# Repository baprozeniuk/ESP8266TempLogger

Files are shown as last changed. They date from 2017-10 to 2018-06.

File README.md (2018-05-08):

# ESP8266 Temperature Logger
Designed and tested on a Lolin NodeMCU V3. Sends temperature over UDP from a DS18B20 connected to an ESP8266 microcontroller.

# Data Format
Temperature is sent in a single UDP packet with a payload of 12 bytes to a configurable host and port. 
First 6 bytes contain the MAC address of the ESP8266 as a unique identifier
Second 2 bytes contain a 16 bit unsigned integer to identify the sensor. Multiple Sensors are not yet supported, so this value is always 0x0000
Final 4 bytes contain a 32 bit floating point value from the sensor in Celsius 

# Configuration
The WiFi network configured in the ESP8266 EEPROM will be used by default. If you have previously programmed the microcontroller, the reset config switch should be activated on first boot. If you have previously programmed a WiFi network and do not reset the controller the host and port will be improperly configured ad the program is likely to crash, or send no data.

The configuration mode is triggered either by closing the reset circuit, or if a wifi connection fails. 

Once in configuration mode, a WiFi network named "ESP8266" will be created. This network will direct you to a captive portal at 192.168.4.1. Enter your WiFi network configuration, server name and port. Make sure that the reset circuit is open before saving otherwise it will re-enter configuration mode upon reboot. 

# Consuming Data
An example Python script is included. 

The script includes alerting via email and amazon SNS, logging to console, database and csv file.

Another example server is located at https://github.com/andrewmacheret/temperature-sensor-server

# Build Dependencies 
 * WiFi Manager: https://github.com/tzapu/WiFiManager
 * OneWire: https://www.pjrc.com/teensy/td_libs_OneWire.html
 * ESP8266 Libraries from: https://github.com/esp8266/Arduino
 * Maxim/Dallas Temperature Library: https://github.com/milesburton/Arduino-Temperature-Control-Library

# Parts Required
 * ESP8266 (ESP12E or ESP12F should work). WEMOS boards also work.
 * DS18B20 1-Wire temperature Sensor
 * 2x 4.7kΩ resistors
 * 1 switch of some type. Needs to be able to be closed for 1 durration of the program
 * 3.3V power supply, or use the voltage regulator configuration described in the wiring diagram and cad files
 
 # Wiring Diagram
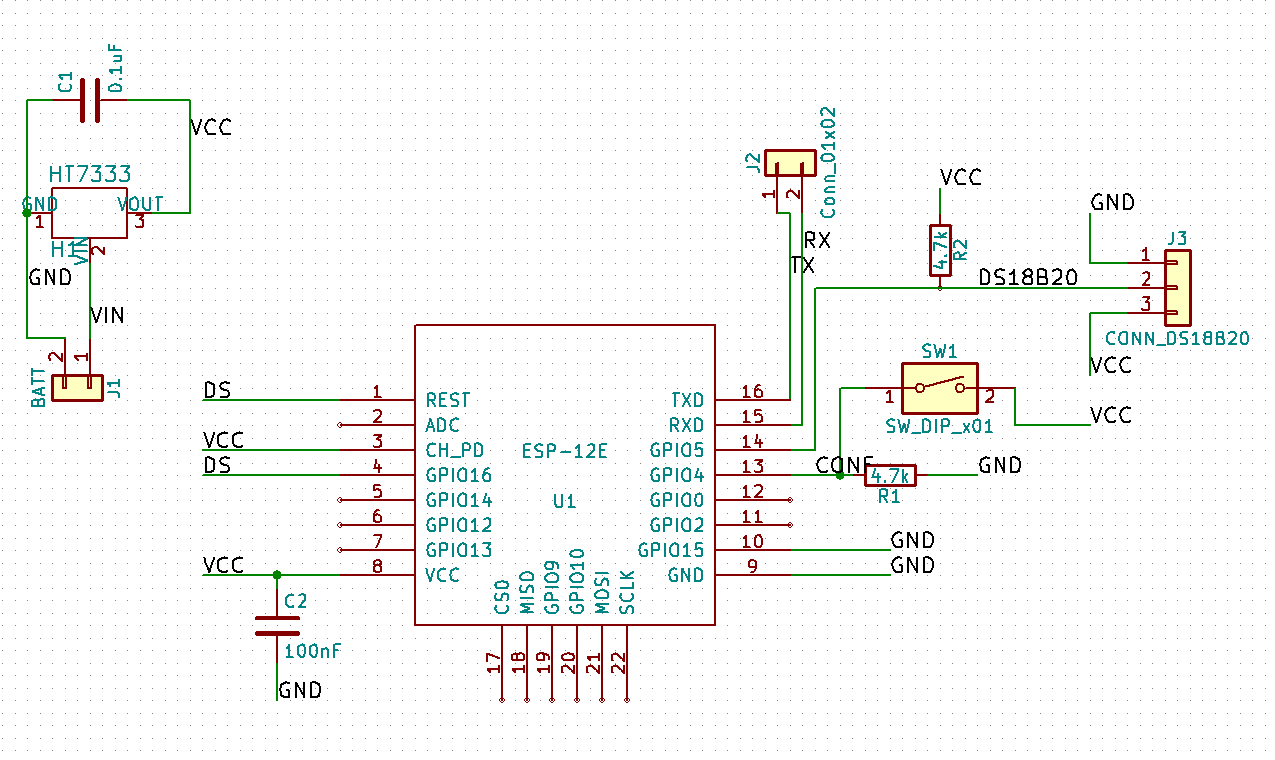
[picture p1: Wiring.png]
schematic Wiring Diagram


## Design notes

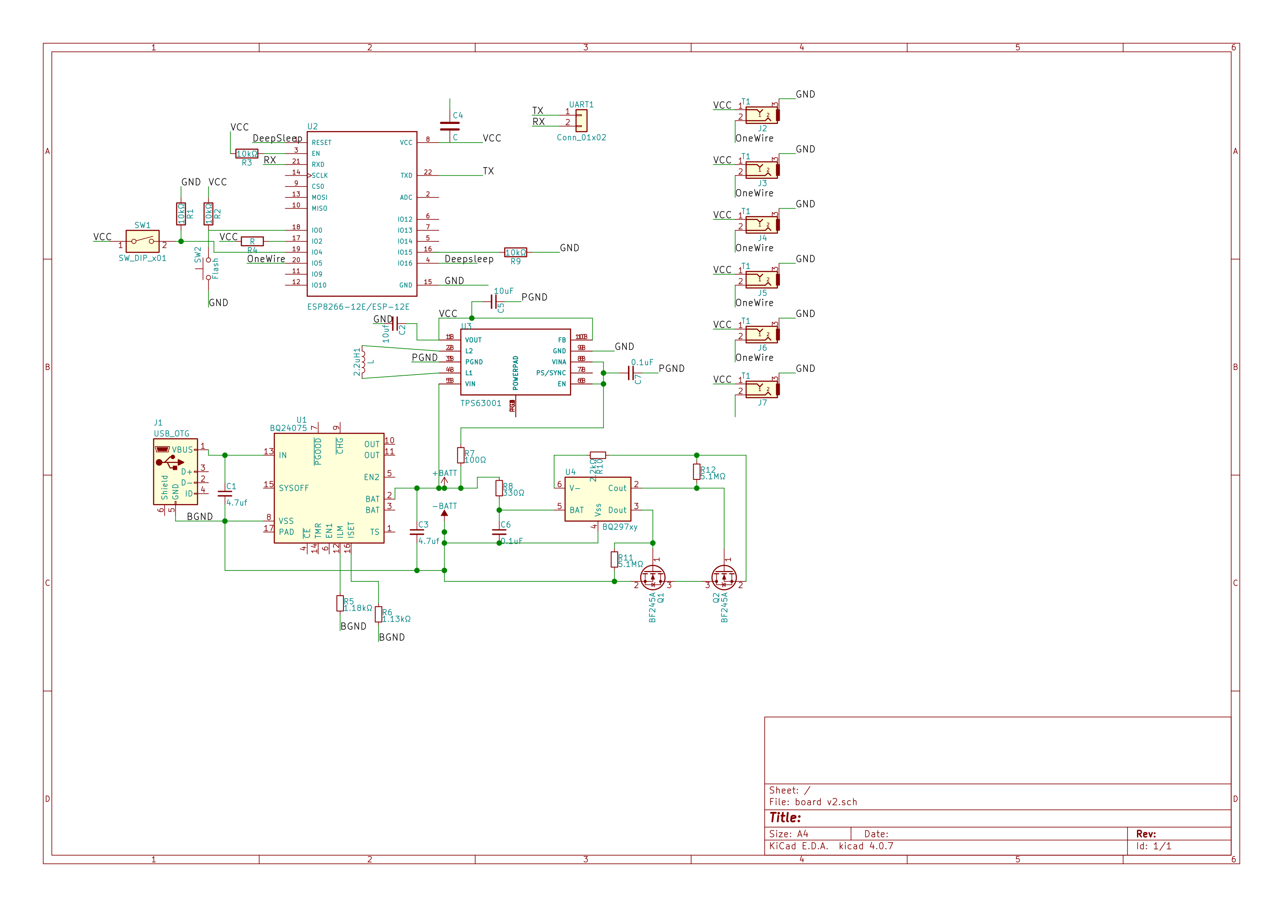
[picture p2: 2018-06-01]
Board V2/board v2.sch.png

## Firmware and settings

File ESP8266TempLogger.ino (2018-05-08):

#include <DNSServer.h>
#include <ESP8266WiFi.h>
#include <ESP8266WebServer.h>
#include <WiFiManager.h>
#include <OneWire.h>
#include <DallasTemperature.h>
#include <EEPROM.h>

#define ONE_WIRE_BUS 5 // Data wire is plugged into pin D1 (NodeMCU) on the ESP8266 12-E - GPIO 5
#define TRIGGER_PIN 4 // Reset button on D2 / GPIO 4
//#define POWER_PIN 13 // nodeMCU pin D7 / GPIO13 - for powering the DS18B20
#define WAKEUP_PIN 16

char* computer_ip;
int computer_port;
byte mac[6];
OneWire oneWire(ONE_WIRE_BUS); // Start a OneWire Bus
DallasTemperature DS18B20(&oneWire); // Pass our oneWire reference to Dallas Temperature. 
float tempC; //we should be able to pass this around as a reference rather than using a global. 
WiFiUDP UDP; //UDP Socket Instance
unsigned long _connectTimeout = 30000; //time out for wifi connection 1000 * seconds
uint32_t sleeptime = 120e6; //how long to sleep for in mirosecods (seconds e6)

void getTemperature();

void setup() {
  WiFi.macAddress(mac);  // get mac address for use as a serial number
  pinMode(WAKEUP_PIN,WAKEUP_PULLUP);//D0 / GPIO16 is connected to reset for deep sleep wakeup call.
  pinMode(TRIGGER_PIN, INPUT);
  Serial.begin(115200); //enable serial output for debugging. Using this bitrate allows the bootloader messages to be readable


 // pinMode(POWER_PIN, OUTPUT); //set the power pin as output
 // digitalWrite(POWER_PIN, HIGH); // turn on the power pin

  WiFiManager wifiManager;
  WiFiManagerParameter server_ip("server", "server", "server", 40); 
  WiFiManagerParameter server_port("port", "port", "30", 40);
  wifiManager.addParameter(&server_ip);
  wifiManager.addParameter(&server_port);

  if ( digitalRead(TRIGGER_PIN) == HIGH ) { //enter config mode if the reset button is pushed
      Serial.println("config overried entered");
      wifiManager.startConfigPortal("ESP8266");
    }
  else{  
//    wifiManager.autoConnect("ESP8266"); //connect to saved wifi network, if connection fails enter config mode. This should probably be changed to sleep if connection fails.
      WiFi.mode(WIFI_STA);
      if (WiFi.SSID()) {
      ETS_UART_INTR_DISABLE(); //Pulled these 3 lines from WiFManager library: trying to fix connection in progress hanging
      wifi_station_disconnect();
      ETS_UART_INTR_ENABLE();

      WiFi.begin();
      int connRes = waitForConnectResult();
      if(connRes != WL_CONNECTED){
        ESP.deepSleep(sleeptime);
      }
     }
     else {
       Serial.println("No Saved Settings detected. Entering Config Mode");
       wifiManager.startConfigPortal("ESP8266"); //no saved settings found, reverting to config mode
      }
  }
  computer_ip = (char*)server_ip.getValue();
  computer_port = atoi(server_port.getValue());
//  computer_ip = "10.9.9.240"; //hardcode values for testing
//  computer_port = 8030;
  int i; 
  byte* p = (byte*) &computer_port;
  EEPROM.begin(256); //write up to 256 bytes (half of the eeprom)
  if (strcmp(computer_ip,"server") && strlen(computer_ip) < 251){ //write our new values to the eeprom, if they're not too long. We need 5 bytes for the null termination and 4 byte integer
    Serial.println("Writing Settings to EEPROM");
    for (i = 0; i < ((strlen(computer_ip)+1)); i++){ //write hostname byte at a time
      EEPROM.write(i,computer_ip[i]);
    }
    for (int j = 0;j<=3;j++){ //write port number byte at a time, continue from the end of the previous string
    EEPROM.write((i+j), *(p+j));
    }  
    EEPROM.commit(); //write our data from memory to EEPROM. It will stay in RAM, but its no big deal. We don't use much RAM anyway.
  }
  else{
    Serial.println("Reading Settings from EEPROM");
    char currentchar;
    i=0;
    while(currentchar != NULL) //read target host byte at a time, end when we encounter null termination
    {
      currentchar = EEPROM.read(i); 
      computer_ip[i] = currentchar;
      i++;
    }
    for (int j=0;j<=3;j++){  //read port number byte at a time
      *(p+j)  = EEPROM.read(i+j);
    }     
  }
  delay(10); //not sure why we're delaying here. Need to test removing this.
  DS18B20.begin(); //start the sensor 
}

void loop() {
  getTemperature();
  UDP.beginPacket(computer_ip,computer_port);//start a new UDP packet
  for(int i = 0;i <= 5 ;i++){ //write the mac address byte at a time
    UDP.write(mac[i]);
  }
  uint16_t s = 0;
  byte *p = (byte*)&s;
  UDP.write(p[0]); //write sensor ID. Hardcoded to 0000 for now. Needs to be written byte at a time.
  UDP.write(p[1]);
  p = (byte*) &tempC; //write the temperature value byte at a time
  for (int i = 3;i >= 0;i--){
    UDP.write(p[i]);
  }
  UDP.endPacket();//send the packet
 // digitalWrite(POWER_PIN, LOW);
  delay(100); //delay long enough to send the packet before going to sleep. Test reducing this value, we may be able to reduce power consumption
  ESP.deepSleep(sleeptime); //go to sleep for a minute *set to 5s for testing change to 60e6 for 1 minute*
}

void getTemperature() {
  int i=0;
  do {
    DS18B20.requestTemperatures(); 
    tempC = DS18B20.getTempCByIndex(0);
    delay(100); //test reducing this value, we may be able to reduce power consumption
    if (i > 100){
      break;
    }
    i++;
  } while (tempC == 85.0 || tempC == (-127.0));
}



uint8_t waitForConnectResult() { //waits for wifi connection result. Pulled from WifiManager library.
  if (_connectTimeout == 0) {
    return WiFi.waitForConnectResult();
  } else {
    unsigned long start = millis();
    boolean keepConnecting = true;
    uint8_t status;
    while (keepConnecting) {
      status = WiFi.status();
      if (millis() > start + _connectTimeout) {
        keepConnecting = false;
      }
      if (status == WL_CONNECTED || status == WL_CONNECT_FAILED) {
        keepConnecting = false;
      }
      delay(100);
    }
    return status;
  }
}

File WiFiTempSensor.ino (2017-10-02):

#include <DNSServer.h>
#include <ESP8266WebServer.h>
#include <ESP8266WiFi.h>
#include <WiFiManager.h>
#include <OneWire.h>
#include <DallasTemperature.h>
#include <EEPROM.h>

char* computer_ip;
int computer_port;
byte mac[6];

// Data wire is plugged into pin D1 on the ESP8266 12-E - GPIO 5
#define ONE_WIRE_BUS 5
// Reset button on D2 / GPIO 4
#define TRIGGER_PIN 4
// Setup a oneWire instance to communicate with any OneWire devices (not just Maxim/Dallas temperature ICs)
OneWire oneWire(ONE_WIRE_BUS);

// Pass our oneWire reference to Dallas Temperature. 
DallasTemperature DS18B20(&oneWire);

//float tempF;
float tempC;
//char temperatureCString[6];
//boolean wifiConnected = false; // from an older version
WiFiUDP UDP;

void getTemperature();

void setup() {

  WiFi.macAddress(mac);  // get mac address for use as a serial number
  pinMode(TRIGGER_PIN, INPUT);
//  Serial.begin(74880);
//  Serial.print("\n");
//  Serial.println("Starting wifi config");
  WiFiManager wifiManager;
  
  WiFiManagerParameter server_ip("server", "server", "server", 40);
  WiFiManagerParameter server_port("port", "port", "30", 40);
  wifiManager.addParameter(&server_ip);
  wifiManager.addParameter(&server_port);

  if ( digitalRead(TRIGGER_PIN) == HIGH ) {
//    Serial.println("Reset Trigger detected, entering config mode");
      wifiManager.startConfigPortal("ESP8266");
//      Serial.println("connected...yeey :)");
    }
  else{  
    wifiManager.autoConnect("ESP8266"); //connect to saved wifi network, if connection fails enter config mode. This should probably be changed to sleep if connection fails.
  }
  computer_ip = (char*)server_ip.getValue();
  computer_port = atoi(server_port.getValue());
//  computer_ip = "10.9.9.240";
//  computer_port = 8030;
  int i;
  byte* p = (byte*) &computer_port;
  EEPROM.begin(256); //write up to 256 bytes (half of the eeprom)
  if (strcmp(computer_ip,"server") && strlen(computer_ip) < 251){ //write our new values to the eeprom, if they're not too long. We need 5 bytes for the null termination and 4 byte integer
//    Serial.println("Writing New Data to EEPROM");
    for (i = 0; i < ((strlen(computer_ip)+1)); i++){ //write hostname byte at a time
      EEPROM.write(i,computer_ip[i]);
//      Serial.println("Writing byte containing");
//      Serial.println(computer_ip[i]);
    }
    for (int j = 0;j<=3;j++){ //write port number byte at a time
    EEPROM.write((i+j), *(p+j));
//      Serial.print("Writing byte containing:");
//      Serial.println(*(p+j));
    }  
    EEPROM.commit();
  }
  else{
//    Serial.println("Reading data from EEPROM");
    char currentchar;
    i=0;
    while(currentchar != NULL) //read target host byte at a time, end when we encounter null termination
    {
      currentchar = EEPROM.read(i);
  //    Serial.println("Reading byte containing");
  //    Serial.println(currentchar);   
      computer_ip[i] = currentchar;
      i++;
    }
    for (int j=0;j<=3;j++){  //read port number byte at a time
    *(p+j)        = EEPROM.read(i+j);
    //Serial.print("Reading byte containing");
    //Serial.println(*(p+j));
    }     

  }
//  Serial.print("Target Host:");
//  Serial.println(computer_ip);
//  Serial.print("Target Port:");
//  Serial.println(computer_port);
  delay(10);
  DS18B20.begin();
  pinMode(D0,WAKEUP_PULLUP);//D0 / GPIO16 is connected to reset for deep sleep wakeup call.
}

void loop() {
  getTemperature();
  UDP.beginPacket(computer_ip,computer_port);
  for(int i = 0;i <= 5 ;i++){ //write the mac address byte at a time
    UDP.write(mac[i]);
  }
  UDP.write(0x01); //sensor ID number  
  byte *p = (byte*) &tempC; //write the temperature value byte at a time
  for (int i = 3;i >= 0;i--){
    UDP.write(p[i]);
  }
  UDP.endPacket();//send the packet
  delay(100); //delay long enough to send the packet before going to sleep
  ESP.deepSleep(5e6); //go to sleep
}

void getTemperature() {
  do {
//    Serial.println("Requesting Temp");
    DS18B20.requestTemperatures(); 
    tempC = DS18B20.getTempCByIndex(0);
    delay(100);
  } while (tempC == 85.0 || tempC == (-127.0));
}

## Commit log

2017-10-02 renamed arduino file and increased temperature sensor ID lenght from 8 bits to 16 bits.
2017-10-06 Changed Wifi Conection to sleep rather than enter config mode upon connection failure. Added timeout for sensor at about 10 seconds.
    [ESP8266TempLogger.ino]
2018-05-08 arduino code fixes to be consistent with final design, test server updated with alerting (sms and email) and database logging
    [ESP8266TempLogger.ino]
2018-05-08 added kicad files
    [ds18b20board-B.Cu.gbr, ds18b20board-B.Mask.gbr, ds18b20board-B.SilkS.gbr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]
2018-05-08 updated wiring diagram
2018-05-12 added web application for getting results from the DB and setting friendly names for sensors
2018-06-01 added files for new version of the PCB
    [board v2.kicad_pcb, board v2.sch]
2018-06-01 added png of schematic
